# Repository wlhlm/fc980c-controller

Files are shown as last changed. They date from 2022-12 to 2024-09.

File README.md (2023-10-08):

Leopold FC980C Replacement Controller
=====================================

This PCB replaces the controller of the Leopold FC980C keyboard to allow running
alternate firmware, especially open source firmware such as [QMK][QMK]. This
project relies heavily on the prior reverse engineering work done by hasu (aka
tmk) and collaborators.

This is the first PCB I have designed and as such I suspect this will have many
areas that can be improved. I am very much looking forward to hearing feedback
about this design, if you think something can be improved please open an issue
and let me know. I will list my reasons for various design choices below, as
well as an errata section to list shortcomings of the current design that I am
aware of.

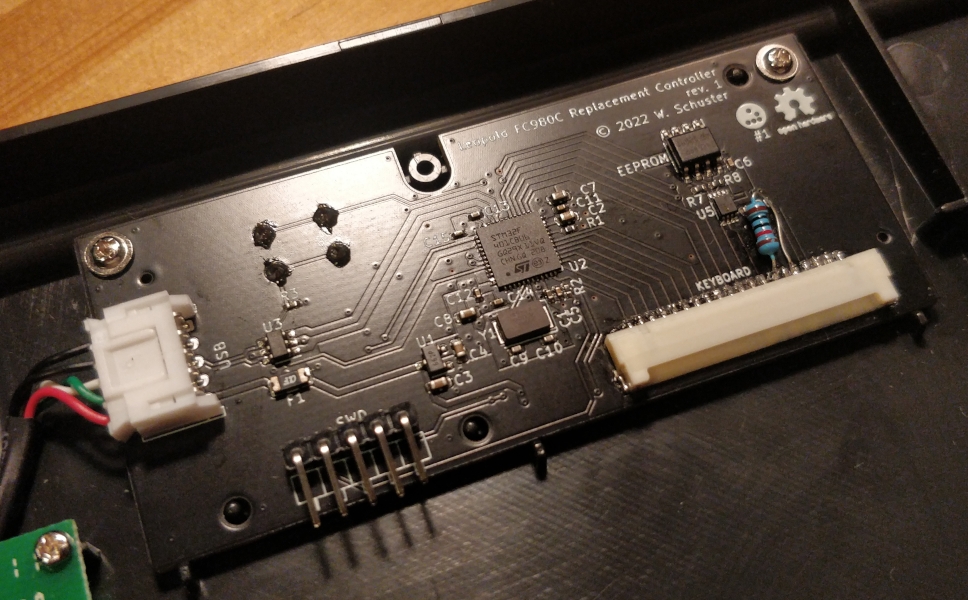
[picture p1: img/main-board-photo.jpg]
FC980C controller photo

(the resistor hand-soldered to the connector is due to a flaw of the revision 1
design, which has been fixed in revision 2)

**Specs:**
- STM32F401 MCU as found on the Blackpill boards
- Open Hardware licensed under CERN OHL-S v2
- designed to be assembled by [JLCPCB][JLC] (can of course be manufactured
  elsewhere, but board component selection has been optimized for JLC's
  component library)

**Why would anyone want a replacement keyboard controller for the FC980C?** In
case the original controller gets fried, the lack of controller replacement from
the manufacturer would otherwise mean tossing the whole (expensive) keyboard.
This board enables the usage of Free and Open Source firmware to replace the
proprietary stock firmware. Running alternate firmware allows enabling hardware
features not accessible through the original controller such as actuation point
adjustments, not to mention the plethora of software features enabled by QMK for
example.

[QMK]: https://qmk.fm/
[JLC]: https://jlcpcb.com/

Getting started
---------------

If you have received this controller fully assembled, your next step will be
firmware setup. Check the `firmware/` directory in this repository.

In case you still have to solder on the connectors, see the assembly section
below.

Assembly
--------

This PCB is intended to be manufactured and assembled by JLCPCB, **except** for
the connectors and a button on the back of the board, which most likely have to
be soldered on the PCB by hand.

The button (labled BOOT0) is through-hole and easily soldered by hand. Make sure
to place it on the bottom side, i.e. opposite side of the MCU, where the DIP
switches are on the original controller board.

The connector for the USB board (USB) is though-hole and can be hand-soldered.

The SWD header is optional and can be left unsoldered.

The connector labeled KEYBOARD is only available for surface mounting and
unfortunately not available at JLC for assembly (at least at the time of
design). Hand-soldering is a bit more challenging for this connector. Make sure
to use a healthy dose of flux and fine gauge solder wire.

Production
----------

While the PCB itself can be manufactured by a number of PCB houses, component
selection and SMD assembly is made with [JLCPCB][JLC] in mind. The
`jlcpcb/production_files` folder for each revision should include the necessary
BOM and CPL files in addition to the Gerbers. The board parameters are specified
in the PCB design file (the main parameters being a board thickness of 1.6mm and
2 copper layers). For the option "Remove Order Number", you can select "Specify
a location".

This board is compatible with JLC's "Economic PCBA" option. For option "Assembly
Side", choose "Top Side" and under "Tooling holes" you can specify "Added by
Customer".

The EEPROM (U4) and accompanying decoupling capacitor (C6) are optional. The
board should work without those populated.

[JLC]: https://jlcpcb.com/

Design review
-------------

The specific component selection is tailored to what was available at JLCPCB at
the time of design. While things like the capacitors and resistors can be easily
substituted, Larger ICs such as the USB protection, fuse, 3.3V regulator, and
MCU have not been evaluated for alternative parts.

The USB and KEYBOARD connectors interface with the existing connectors used in
the FC980C and cannot be substituted.

I don't intend to sell this controller PCB by myself and as such everyone who is
interested in the design is meant to order this directly from JLC for
themselves. As such, I've tried to minimize cost for low quantity production
runs. JLC has the concept of extended and basic parts where the former incurs a
one-time setup fee per production rund per component as those components require
additional labor for setting up the pick and place machines with the respective
components. I've tried to keep the number of extended components as low as
possible.

### MCU

The main requirements for the microcontroller were 5V tolerance and good
compatibility with QMK. I also tried to take pricing and availability for the
foreseeable future into account. My choice fell on the STM32F401 that is used in
the cheap "Blackpill" development boards. It is well supported by QMK and is
also used in [another Topre controller board project][RFR1Replacement] that
replaces the PCB of the Realforce R1 TKL keyboards.

[RFR1Replacement]: https://github.com/Cipulot/RF_R1_8-9Xu

### Protection circuitry

The 5V fuse and USB protection components have been carried forward from the
original RP2040-based design (revision 1) and have been taken from
[this][RP2040DesignGuide] RP2040 design guide.

[RP2040DesignGuide]: https://github.com/Sleepdealr/RP2040-designguide

### USB traces

USB trace width has been calculated using the KiCad built-in calculator
following a [guide on the Digikey blog][DigikeyUSBTraceGuide]. The wide traces
are caused by the board design having two layers and a thickness of 1.6mm.  This
is most likely overkill as the bandwidth requirements are very low for a
keyboard. Reviewing a number of other boards, none were using USB-specific trace
widths.

[DigikeyUSBTraceGuide]: https://www.digikey.de/en/maker/projects/how-to-route-differential-pairs-in-kicad-for-usb/45b99011f5d34879ae1831dce1f13e93

Errata
------

### Revision 2

None found thus far.

### Revision 1

The SWD header is unusable since SWDIO has been routed to the wrong pin on the
MCU (PA15 instead of PA13). This has no impact on the actual controller
functionality. Fixed in revision 2.

Unfortunately, the `KEY_STATE` pin is missing a 5V pull-up resistor. A manual
fix (such as soldering a 10k resistor between the `KEY_STATE` \[pin 14\] and 5V
pins on the `KEYBOARD` connector) is necessary. Fixed in revision 2.

Revisions
---------

### Revision 2

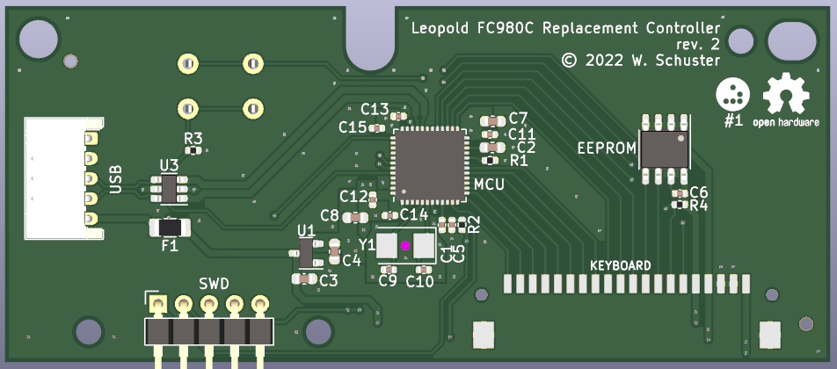
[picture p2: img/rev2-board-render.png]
rev2 PCB


Updates SWD pinout to correctly use PA13 on the MCU for SWDIO instead of PA15.

Minor position adjustments to drill holes.

Adds 5V pull-up resistor to `KEY_STATE` line.

Removes I2C level shifter to simplify BOM.

**Sample tested and working:** not yet—it is recommended to enable the options
"Confirm Production file" and "Confirm Parts Placement" when ordering from
JLC

### Revision 1

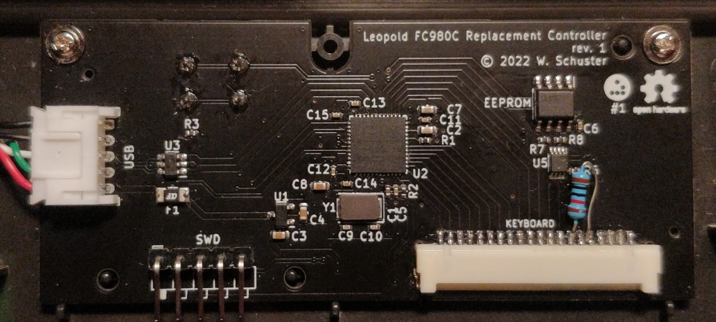
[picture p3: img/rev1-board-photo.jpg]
rev1 PCB


First design that has a chance to actually work in the FC980C. Switch to a
STM32F401 microcontroller. This MCU allows saving a couple of components
compared to the RP2040, such as USB termination resistors and external flash.

One notable addition compared to the previous revision is an optional 64Kb
EEPROM.

**Sample tested and working:** tested and issues identified (see Errata
section), working with the suggested manual fixes

### Revision 0

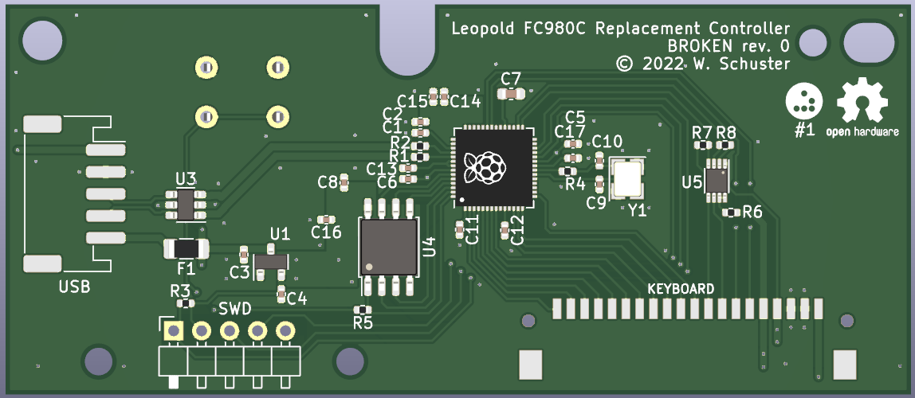
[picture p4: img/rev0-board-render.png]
rev0 PCB


The first version of this PCB uses a RP2040 controller. Unfortunately, the
FC980C electronics rely on the MCU being 5V tolerant. I have noticed this only
while triple checking the design *just* before submitting it for manufacturing.
The RP2040 is *not* 5V tolerant and would require level shifters on many I/O
lines. Because of that I decided to scrap the design and start anew, but since
the board design was pretty much complete, I'm including it in this repository
for posterity.

**Sample tested and working:** no

Acknowledgements
----------------

This replacement controller relies heavily on the [prior reverse engineering
work][GeekhackFC980CInvestigation] of the keyboard community, including
uncovering [schematics][FC660CSchematics] for the similar Leopold FC660C that
were submitted to the FCC that helped me figure out the I/O voltage
requirements. In particular, I want to thank hasu (aka tmk) who created a FC980C
replacement controller based on the ATmega32u4 MCU, publishing schematics and an
[open source firmware implementation][TMKFC980C] for tmk that has been
[ported][QMKFC980C] to QMK.

Thanks to Toocanzs#5098 from the QMK Discord for helping me with the crystal
load capacitor calculation.

The PCB has been designed using KiCad 6 and production files have been exported
using [Bouni's JLCPCB tools plugin][BouniJLCPlugin].

[GeekhackFC980CInvestigation]: https://geekhack.org/index.php?topic=90681.0
[FC660CSchematics]: https://fccid.io/pdf.php?id=1888185
[TMKFC980C]: https://github.com/tmk/tmk_keyboard/tree/master/keyboard/fc980c
[QMKFC980C]: https://github.com/qmk/qmk_firmware/tree/f21443d6a2be8e2068164f0f3646a175ffed2df4/keyboards/fc980c
[BouniJLCPlugin]: https://github.com/Bouni/kicad-jlcpcb-tools

Resources
---------

These are various resources, that helped me designing my first PCB:

- STM AN4488 - Getting started with STM32F4xxxx MCU hardware development
- [I2C pullup recommendation by adafruit](https://learn.adafruit.com/working-with-i2c-devices/pull-up-resistors),
  [I2C pullup calculator](http://lembke.eu/arduinoablage/20201103i2cpullupcalculator/)
- [I2C Design Mathematics: Capacitance and Resistance](https://www.allaboutcircuits.com/technical-articles/i2c-design-mathematics-capacitance-and-resistance/)
- [Can an STM32 chip directly interface with a 5V I2C bus?](https://electronics.stackexchange.com/questions/50435/can-i-directly-interface-to-5v-i2c-devices-with-an-stm32-running-on-1-8v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)
- [5V to 3.3V logic level translation/conversion/shifting](https://next-hack.com/index.php/2017/09/15/how-to-interface-a-5v-output-to-a-3-3v-input/)
- STM AN2867 - Oscillator design guide for STM8S, STM8A and STM32
  microcontrollers
- [Crystal capacitor guide by adafruit](https://blog.adafruit.com/2012/01/24/choosing-the-right-crystal-and-caps-for-your-design/)
- [STM32 Oscillator Calculator](https://helios.wh2.tu-dresden.de/~benni_koch/stmcalculator/)
- [Crystal Oscillator Design](https://hoani.net/posts/blog/2017-01-19-oscillator-design/)
- [Can the STM32-internal pull-up resistors be used with 5V lines?](http://forums.netduino.com/index.php?/topic/10401-guidance-using-5v-signals-with-pull-upspull-downs/)
- [KiCad differential pair routing guide by Digikey](https://www.digikey.de/en/maker/projects/how-to-route-differential-pairs-in-kicad-for-usb/45b99011f5d34879ae1831dce1f13e93)
- [RP2040 hardware design guide by Sleepdealr](https://github.com/Sleepdealr/RP2040-designguide)
- [KiCad 6 STM32 tutorial by Phil's Lab](https://www.youtube.com/watch?v=aVUqaB0IMh4)
- [KiCad PCB tutorial by MalphasWats](https://github.com/MalphasWats/hawk)
- [Layout Design Guide by Toradex](https://docs.toradex.com/102492-layout-design-guide.pdf)
- [Effective PCB Design by NXP](https://www.nxp.com/files-static/training_pdf/WBNR_PCBDESIGN.pdf)

This helped with the software matrix scanning implementation:

- [Using STM32 GPIO with ChibiOS PAL Driver](https://www.playembedded.org/blog/stm32-gpio-chibios-pal/)

This helped me immensensly in figuring out the FC980C-specific hardware
requirements for the FC980C controller:

- [FC980C pinout](https://github.com/tmk/tmk_keyboard/blob/4df8a27f7220c5f801f16151d31d4db8e563c2fa/keyboard/fc980c/README.md) by tmk
- FC660C [schematic](https://fccid.io/pdf.php?id=1888185) and [BOM](https://fccid.io/pdf.php?id=1888184)

License
-------

Copyright © 2022 Wilhelm Schuster

This PCB design is licensed under the CERN-OHL-S v2. See the LICENSE file in
each of the revision folders for the license text. This license is strongly
reciprocal and is similar in spirit to the GPL, but specifically focuses on
hardware.

The firmware portion of this project is licensed under GPL-2-or-later in
accordance with the QMK project. See the LICENSE file in the firmware folder for
the license text.

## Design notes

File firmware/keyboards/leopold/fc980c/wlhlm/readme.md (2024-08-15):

# Leopold FC980C replacement controller

wlhlm FC980C replacement controller render

* Keyboard Maintainer: [wlhlm](https://github.com/wlhlm)
* Hardware Supported: rev. 1, rev. 2
* [PCB Source](https://github.com/wlhlm/fc980c-controller/)

Make example for this keyboard (after setting up your build environment):

    make leopold/fc980c/wlhlm:default

See the [build environment setup](https://docs.qmk.fm/#/getting_started_build_tools) and the [make instructions](https://docs.qmk.fm/#/getting_started_make_guide) for more information. Brand new to QMK? Start with our [Complete Newbs Guide](https://docs.qmk.fm/#/newbs).

## Flashing the firmware onto the keyboard

To be able to flash the controller, it first has to be brought into bootloader mode. There are three ways this can be accomplished:

- Hold the `BOOT0` button at the back of the controller board (also accessible with the case installed) pressed while plugging the board into USB.
- Hold the `Escape` key while plugging the board into USB (requires QMK to already be flashed onto the controller).
- Press `Fn+Esc` (requires QMK to already be flashed onto the controller).

After entering bootloader mode, new firmware can be flashed. Make example for flashing this keyboard:

    make leopold/fc980c/wlhlm:default:flash

## Actuation point adjustment

Topre keyboards such as the FC980C are based around capacitive sense and allow adjustment of the actuation point. This feature is not supported by the stock FC980C controller, this replacement controller however unlocks said functionality. Check the `actuation_point_example` keymap for guidance.

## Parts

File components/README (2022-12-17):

This contains KiCad parts libraries required for the FC980C controller PCB.

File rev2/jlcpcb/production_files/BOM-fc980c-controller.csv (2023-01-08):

Comment | Designator | Footprint | LCSC
8MHz Cl 20pF | Y1 | Crystal_SMD_5032-2Pin_5.0x3.2mm | C115962
STM32F401CBUx | U2 | QFN-48-1EP_7x7mm_P0.5mm_EP5.6x5.6mm | C118825
100nF | C11,C12,C13,C14,C15,C5,C6 | C_0402_1005Metric | C1525
20pF | C10,C9 | C_0402_1005Metric | C1554
USB | J2 | JST_PH_S5B-PH-K_1x05_P2.00mm_Horizontal | C157923
1uF | C3,C4,C8 | C_0603_1608Metric | C15849
4.7uF | C2 | C_0603_1608Metric | C19666
10uF | C7 | C_0603_1608Metric | C19702
10k | R1,R2,R3,R4 | R_0402_1005Metric | C25744
USBLC6-2SC6 | U3 | SOT-23-6 | C2827654
BOOT0 | SW1 | SW_PUSH_6mm | C2834895
KEYBOARD | J3 | HRS_DF14_20P | C506679
1uF | C1 | C_0402_1005Metric | C52923
XC6206P332MR | U1 | SOT-23 | C5446
500mA | F1 | Fuse_1206_3216Metric | C70076
M24C64-RMN6TP | U4 | SOIC-8_3.9x4.9mm_P1.27mm | C79988
SWD | J1 | PinHeader_1x05_P2.54mm_Horizontal

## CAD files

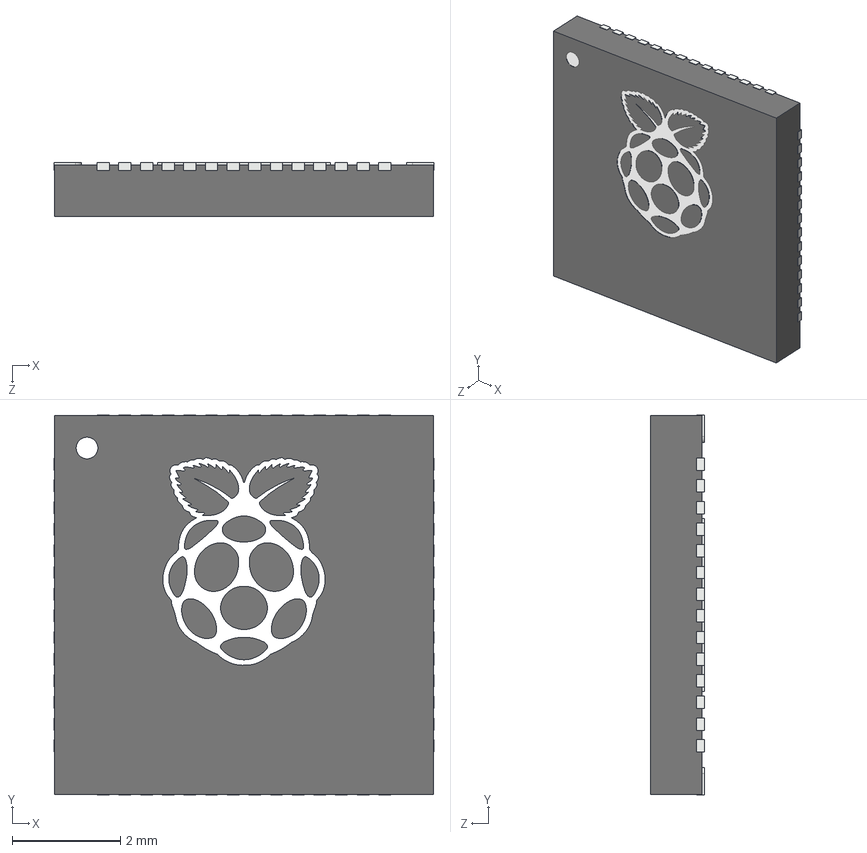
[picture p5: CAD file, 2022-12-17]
components/sleep-lib/RP2040_QFN_PACKAGE.step
7.02 x 7.02 x 1.00 mm

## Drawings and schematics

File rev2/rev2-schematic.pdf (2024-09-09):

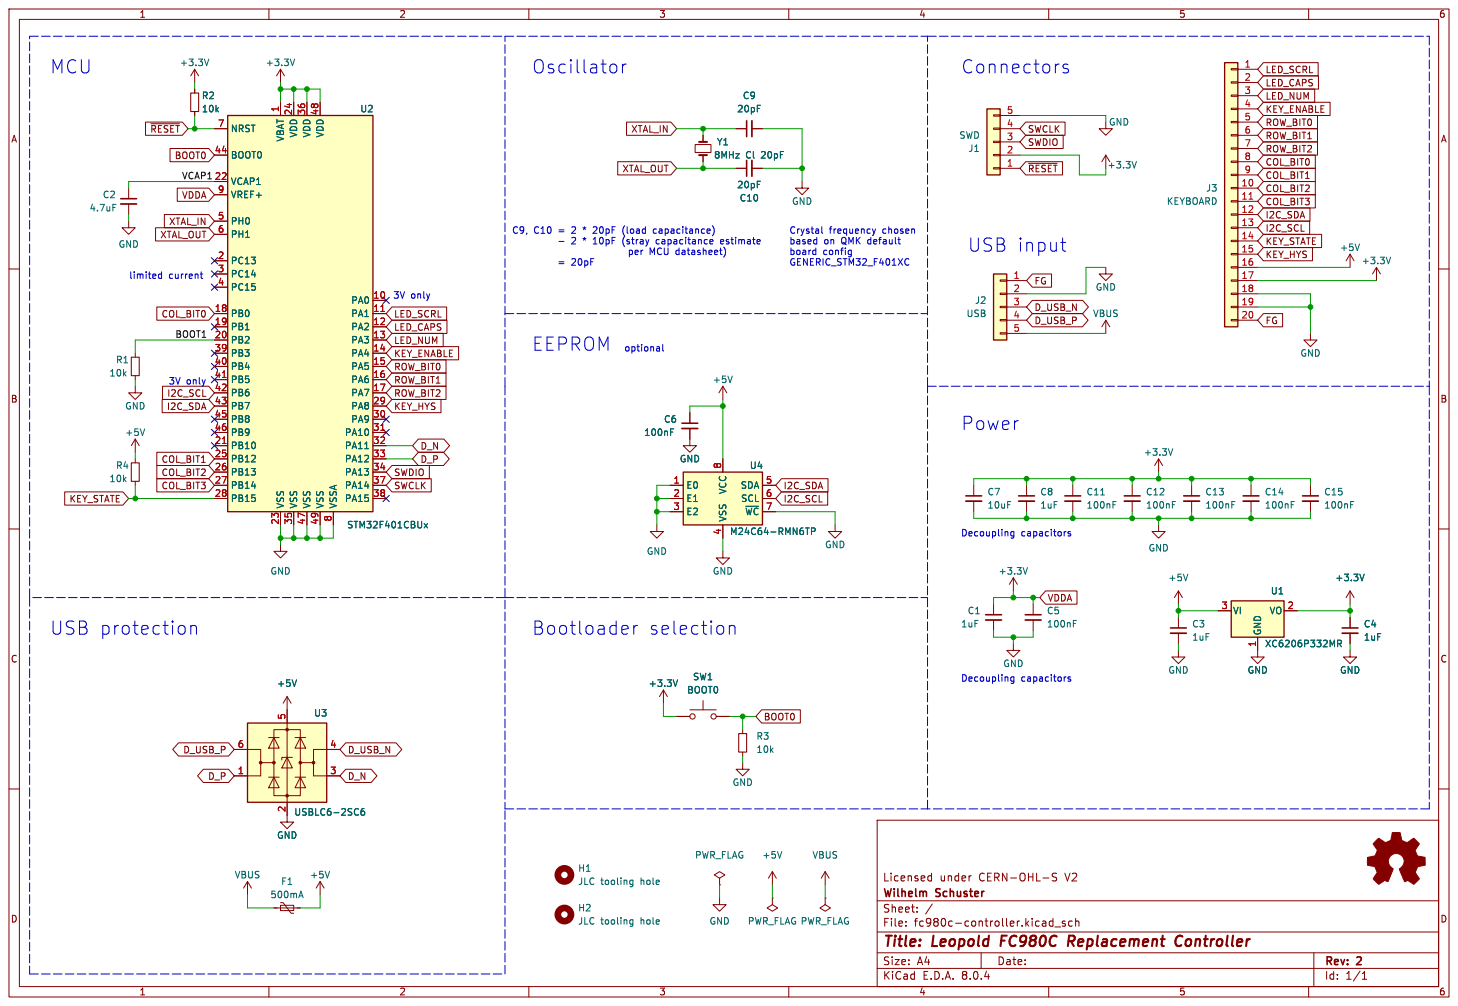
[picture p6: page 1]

1 PA0 10 PA1 11 PA2 12 PA3 13 PA4 14 PA5 15 PA6 16 PA7 17 PB0 18 PB1 19 PC13 2 PB2 20 PB10 21 VCAP1 22 VSS 23 VDD 24 PB12 25 PB13 26 PB14 27 PB15 28 PA8 29 PC14 3 PA9 30 PA10 31 PA11 32 PA12 33 PA13 34 VSS 35 VDD 36 PA14 37 PA15 38 PB3 39 PC15 4 PB4 40 PB5 41 PB6 42 PB7 43 BOOT0 44 PB8 45 PB9 46 VSS 47 VDD 48 VSS 49 PH0 5 PH1 6 NRST 7 VSSA

4 SDA 5 SCL 6 ~{WC}7 VCC

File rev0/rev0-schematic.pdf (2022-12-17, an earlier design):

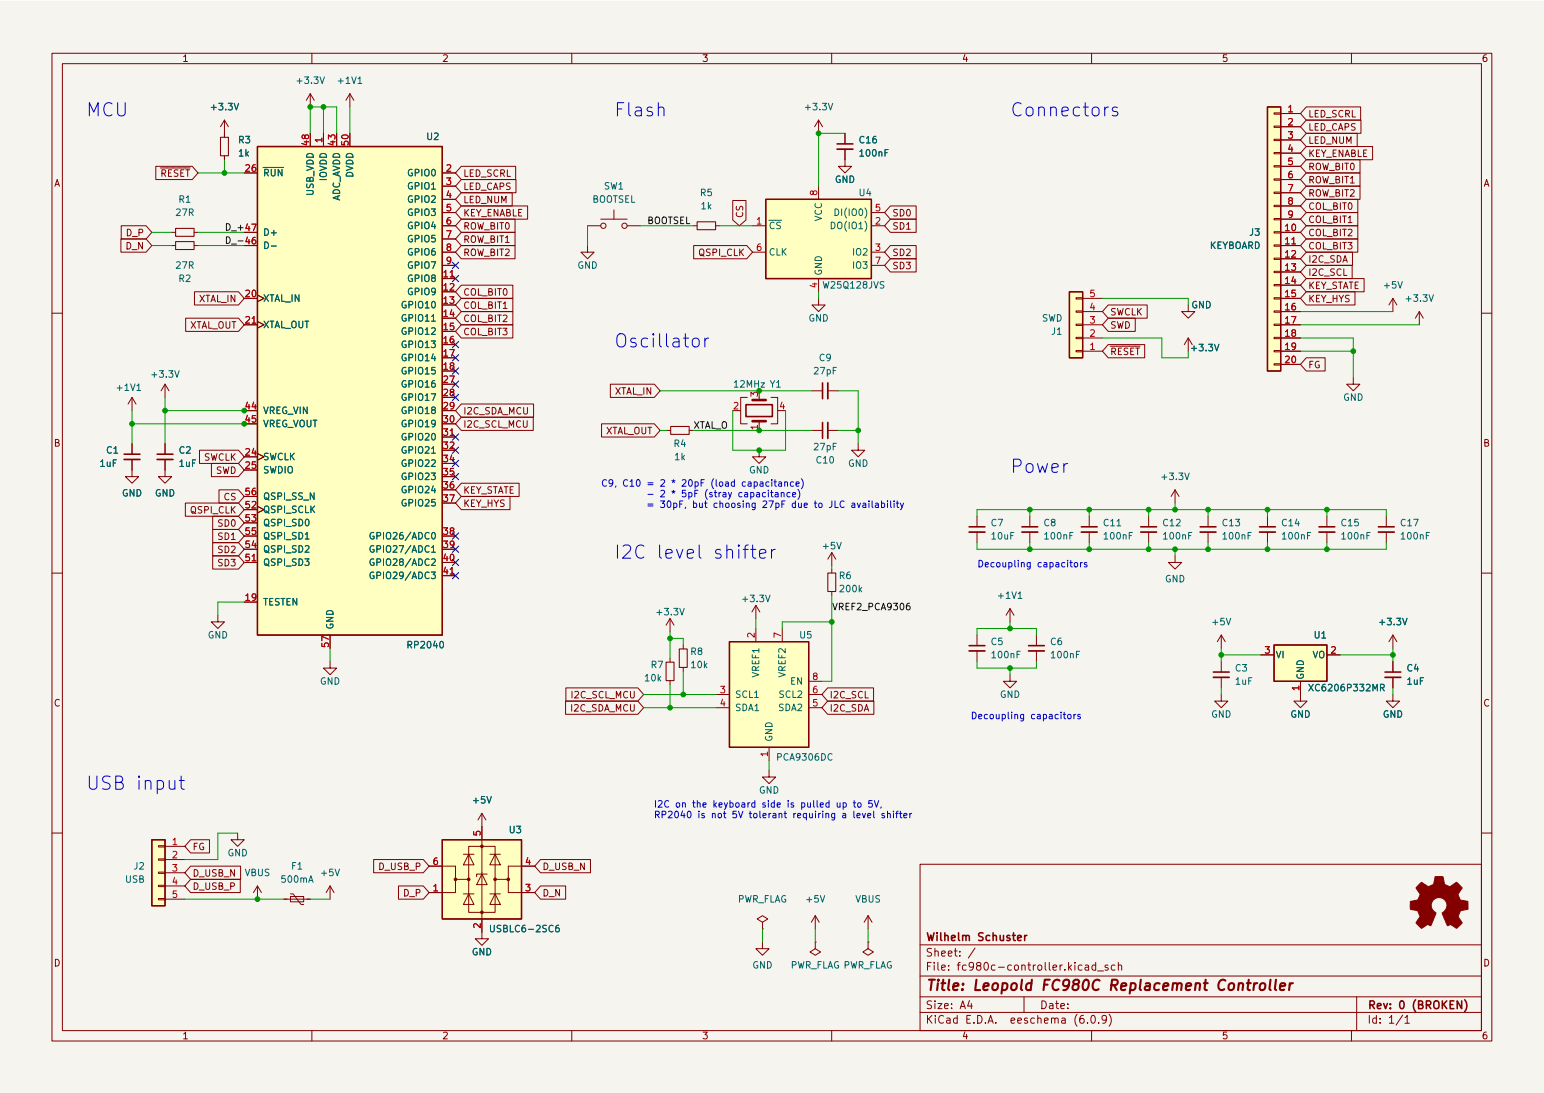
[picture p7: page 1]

1 GPIO8 11 GPIO9 12 GPIO10 13 GPIO11 14 GPIO12 15 GPIO13 16 GPIO14 17 GPIO15 18 TESTEN 19 GPIO0 2 XTAL_IN 20 XTAL_OUT 21 SWCLK 24 SWDIO 25 ~{RUN} 26 GPIO16 27 GPIO17 28 GPIO18 29 GPIO1 3 GPIO19 30 GPIO20 31 GPIO21 32 GPIO22 34 GPIO23 35 GPIO24 36 GPIO25 37 GPIO26/ADC0 38 GPIO27/ADC1 39 GPIO2 4 GPIO28/ADC2 40 GPIO29/ADC3 41 ADC_AVDD 43 VREG_VIN 44 VREG_VOUT 45 D- 46 D+ 47 USB_VDD 48 GPIO3 5 DVDD 50 QSPI_SD3 51 QSPI_SCLK 52 QSPI_SD0 53 QSPI_SD2 54 QSPI_SD1 55 QSPI_SS_N 56 GND 57 GPIO4 6 GPIO5 7 GPIO6 8 GPIO7 9 U2 RP2040 C6

1 GPIO8 11 GPIO9 12 GPIO10 13 GPIO11 14 GPIO12 15 GPIO13 16 GPIO14 17 GPIO15 18 TESTEN 19 GPIO0 2 XTAL_IN 20 XTAL_OUT 21 SWCLK 24 SWDIO 25 ~{RUN} 26 GPIO16 27 GPIO17 28 GPIO18 29 GPIO1 3 GPIO19 30 GPIO20 31 GPIO21 32 GPIO22 34 GPIO23 35 GPIO24 36 GPIO25 37 GPIO26/ADC0 38 GPIO27/ADC1 39 GPIO2 4 GPIO28/ADC2 40 GPIO29/ADC3 41 ADC_AVDD 43 VREG_VIN 44 VREG_VOUT 45 D- 46 D+ 47 USB_VDD 48 GPIO3 5 DVDD 50 QSPI_SD3 51 QSPI_SCLK 52 QSPI_SD0 53 QSPI_SD2 54 QSPI_SD1 55 QSPI_SS_N 56 GND 57 GPIO4 6 GPIO5 7 GPIO6 8 GPIO7 9 +5V GND

C9, C10 = 2 * 20pF (load capacitance)
- 2 * 5pF (stray capacitance)
= 30pF, but choosing 27pF due to JLC availability

I2C on the keyboard side is pulled up to 5V,
RP2040 is not 5V tolerant requiring a level shifter

File: fc980c-controller.kicad_sch Sheet: / Wilhelm Schuster

Id: 1/1 Title: Leopold FC980C Replacement Controller

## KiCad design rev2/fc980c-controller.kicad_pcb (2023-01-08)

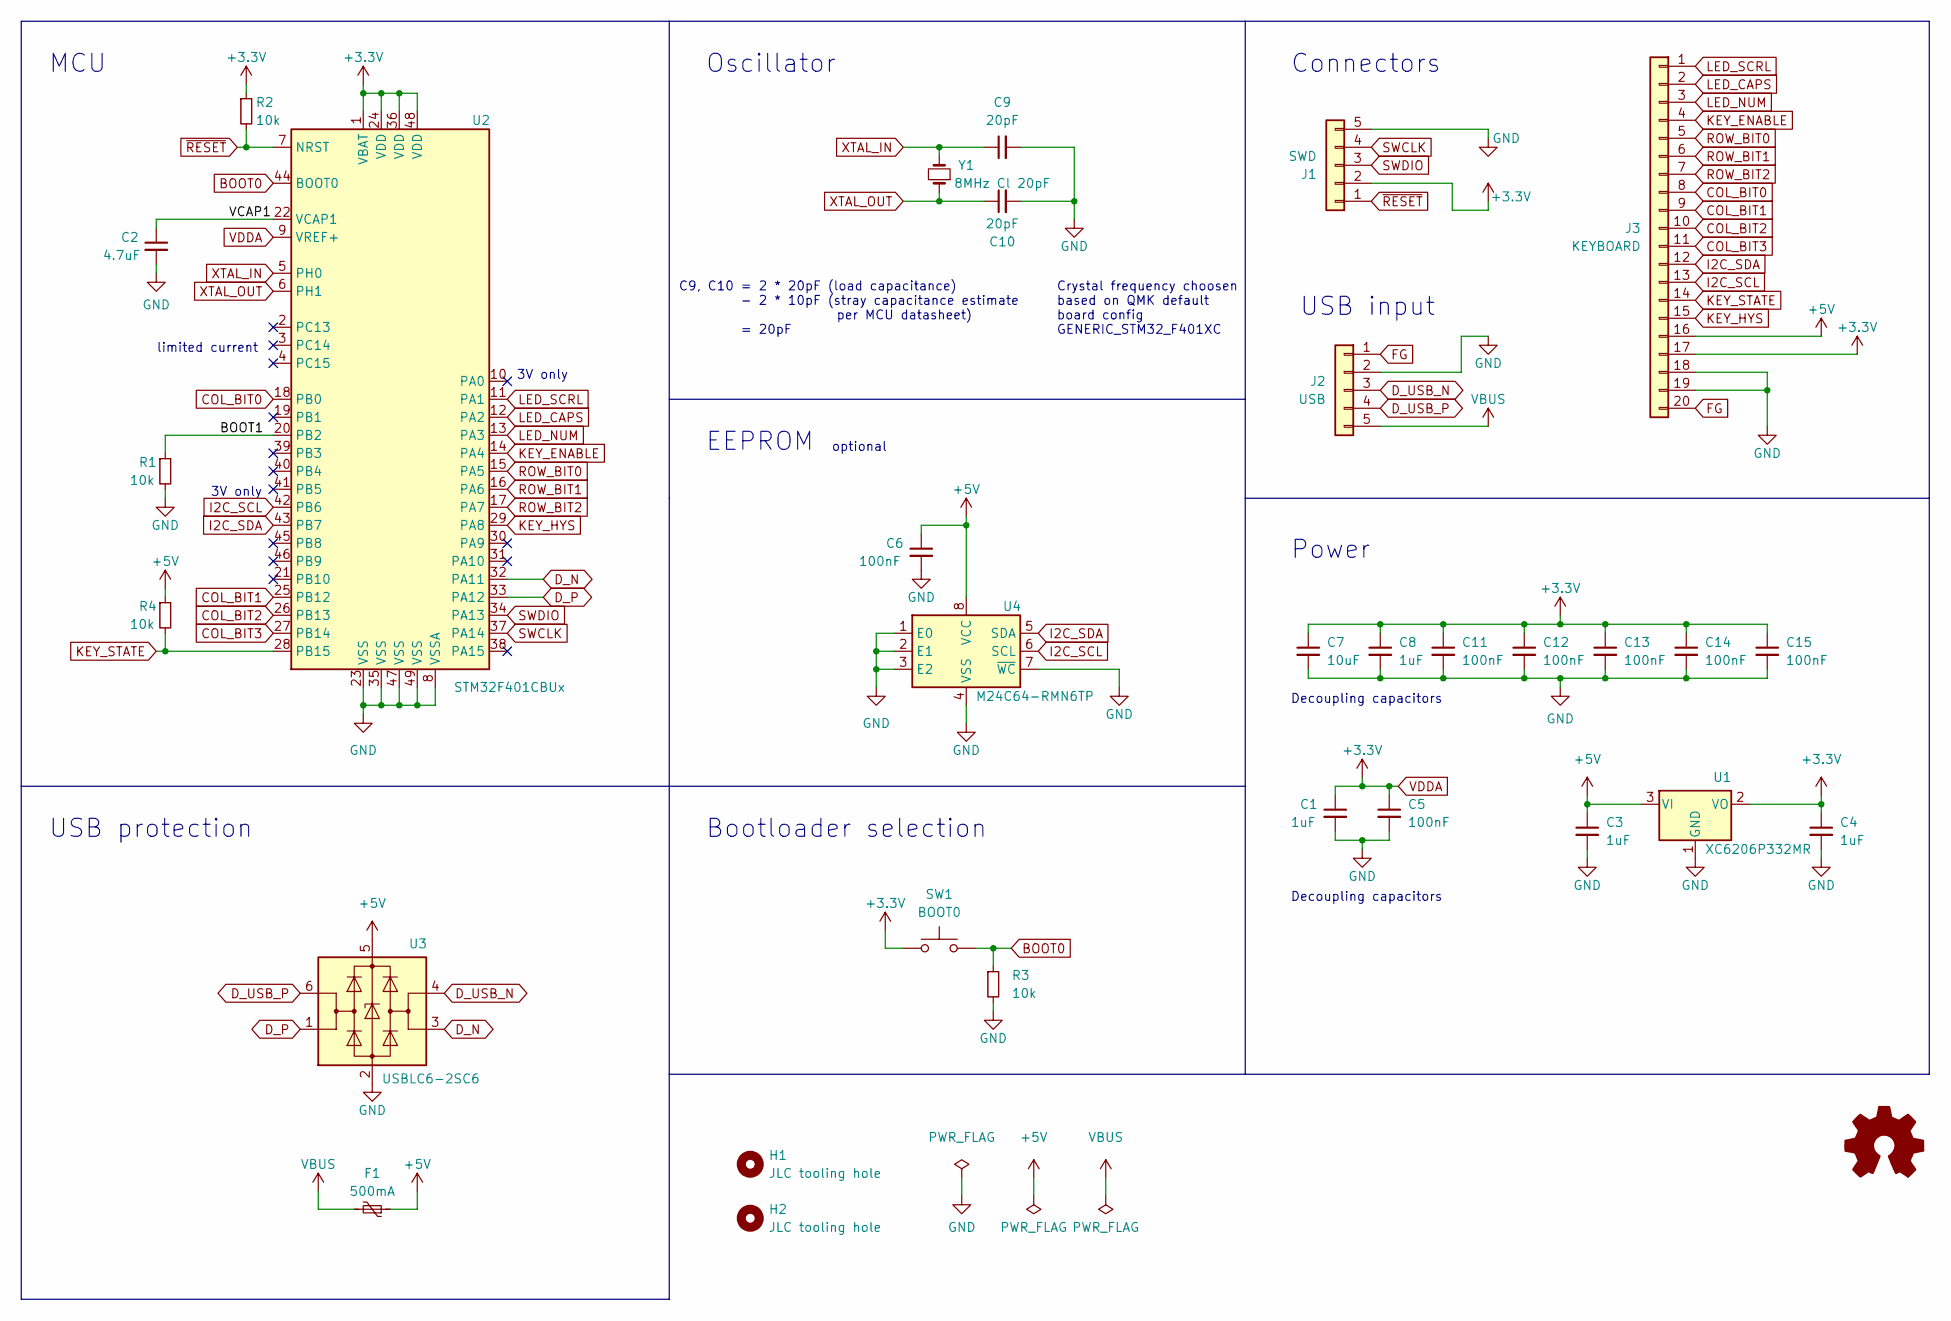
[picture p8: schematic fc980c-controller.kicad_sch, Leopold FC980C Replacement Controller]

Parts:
C1: 1uF; C_0402_1005Metric
C2: 4.7uF; C_0603_1608Metric
C3, C4, C8: 1uF; C_0603_1608Metric
C5, C6, C11, C12, C13, C14, C15: 100nF; C_0402_1005Metric
C7: 10uF; C_0603_1608Metric
C9, C10: 20pF; C_0402_1005Metric
F1: 500mA; Fuse_1206_3216Metric
H1, H2: JLC tooling hole; JLC_tooling_hole
J1: SWD; PinHeader_1x05_P2.54mm_Horizontal
J2: USB; JST_PH_S5B-PH-K_1x05_P2.00mm_Horizontal
J3: KEYBOARD; HRS_DF14_20P
LOGO1: Logo_Open_Hardware_Small; OSHW-Logo2_7.3x6mm_SilkScreen
R1, R2, R3, R4: 10k; R_0402_1005Metric
SW1: BOOT0; SW_PUSH_6mm
U1: XC6206P332MR; SOT-23
U2: STM32F401CBUx; QFN-48-1EP_7x7mm_P0.5mm_EP5.6x5.6mm
U3: USBLC6-2SC6; SOT-23-6
U4: M24C64-RMN6TP; SOIC-8_3.9x4.9mm_P1.27mm
Y1: 8MHz Cl 20pF; Crystal_SMD_5032-2Pin_5.0x3.2mm

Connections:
+5V: C3.1, C6.1, F1.1, J3.16, R4.1, U1.3 (VI), U3.5 (VBUS), U4.8 (VCC)
/BOOT1: R1.1, U2.20 (PB2)
/VCAP1: C2.1, U2.22 (VCAP1)
BOOT0: R3.1, SW1.2, U2.44 (BOOT0)
COL_BIT0: J3.8, U2.18 (PB0)
COL_BIT1: J3.9, U2.25 (PB12)
COL_BIT2: J3.10, U2.26 (PB13)
COL_BIT3: J3.11, U2.27 (PB14)
D_N: U2.32 (PA11), U3.3 (I/O2)
D_P: U2.33 (PA12), U3.1 (I/O1)
D_USB_N: J2.3, U3.4 (I/O2)
D_USB_P: J2.4, U3.6 (I/O1)
FG: J2.1, J3.20
GND: C1.2, C2.2, C3.2, C4.2, C5.2, C6.2, C7.2, C8.2, C9.2, C10.2, C11.2, C12.2, C13.2, C14.2, C15.2, J1.5, J2.2, J3.18, J3.19, J3.21, J3.22, R1.2, R3.2, U1.1 (GND), U2.8 (VSSA), U2.23 (VSS), U2.35 (VSS), U2.47 (VSS), U2.49 (VSS), U3.2 (GND), U4.1 (E0), U4.2 (E1), U4.3 (E2), U4.4 (VSS), U4.7 (~WC)
I2C_SCL: J3.13, U2.42 (PB6), U4.6 (SCL)
I2C_SDA: J3.12, U2.43 (PB7), U4.5 (SDA)
KEY_ENABLE: J3.4, U2.14 (PA4)
KEY_HYS: J3.15, U2.29 (PA8)
KEY_STATE: J3.14, R4.2, U2.28 (PB15)
LED_CAPS: J3.2, U2.12 (PA2)
LED_NUM: J3.3, U2.13 (PA3)
LED_SCRL: J3.1, U2.11 (PA1)
ROW_BIT0: J3.5, U2.15 (PA5)
ROW_BIT1: J3.6, U2.16 (PA6)
ROW_BIT2: J3.7, U2.17 (PA7)
SWCLK: J1.4, U2.37 (PA14)
SWDIO: J1.3, U2.34 (PA13)
VBUS: F1.2, J2.5
VDDA: C1.1, C4.1, C5.1, C7.1, C8.1, C11.1, C12.1, C13.1, C14.1, C15.1, J1.2, J3.17, R2.1, SW1.1, U1.2 (VO), U2.1 (VBAT), U2.9 (VREF+), U2.24 (VDD), U2.36 (VDD), U2.48 (VDD)
XTAL_IN: C9.1, U2.5 (PH0), Y1.2
XTAL_OUT: C10.1, U2.6 (PH1), Y1.1
~RESET: J1.1, R2.2, U2.7 (NRST)

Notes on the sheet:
Decoupling capacitors
3V only
Oscillator
C9, C10 = 2 * 20pF (load capacitance) - 2 * 10pF (stray capacitance estimate per MCU datasheet) = 20pF
Power
limited current
Bootloader selection
Connectors
Crystal frequency choosen based on QMK default board config GENERIC_STM32_F401XC
USB input
USB protection
optional
MCU
EEPROM

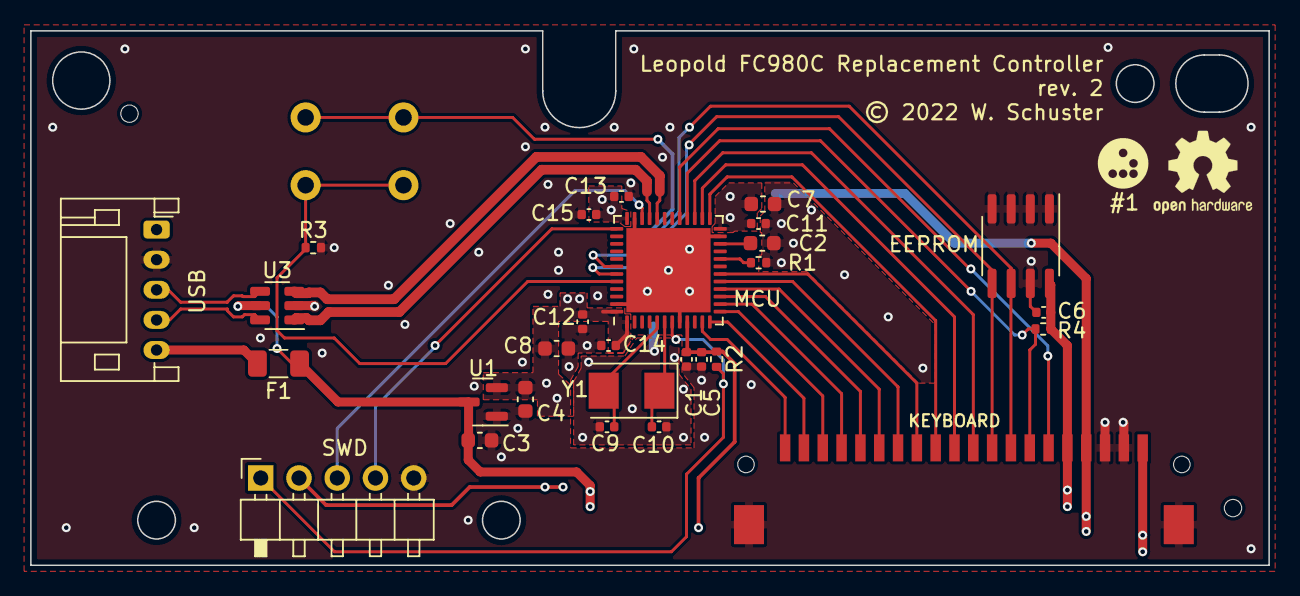
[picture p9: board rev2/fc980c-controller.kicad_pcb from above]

Board: 2 copper layers, 82.2 x 35.5 mm, 32 parts (1 on the bottom side), 32 nets.

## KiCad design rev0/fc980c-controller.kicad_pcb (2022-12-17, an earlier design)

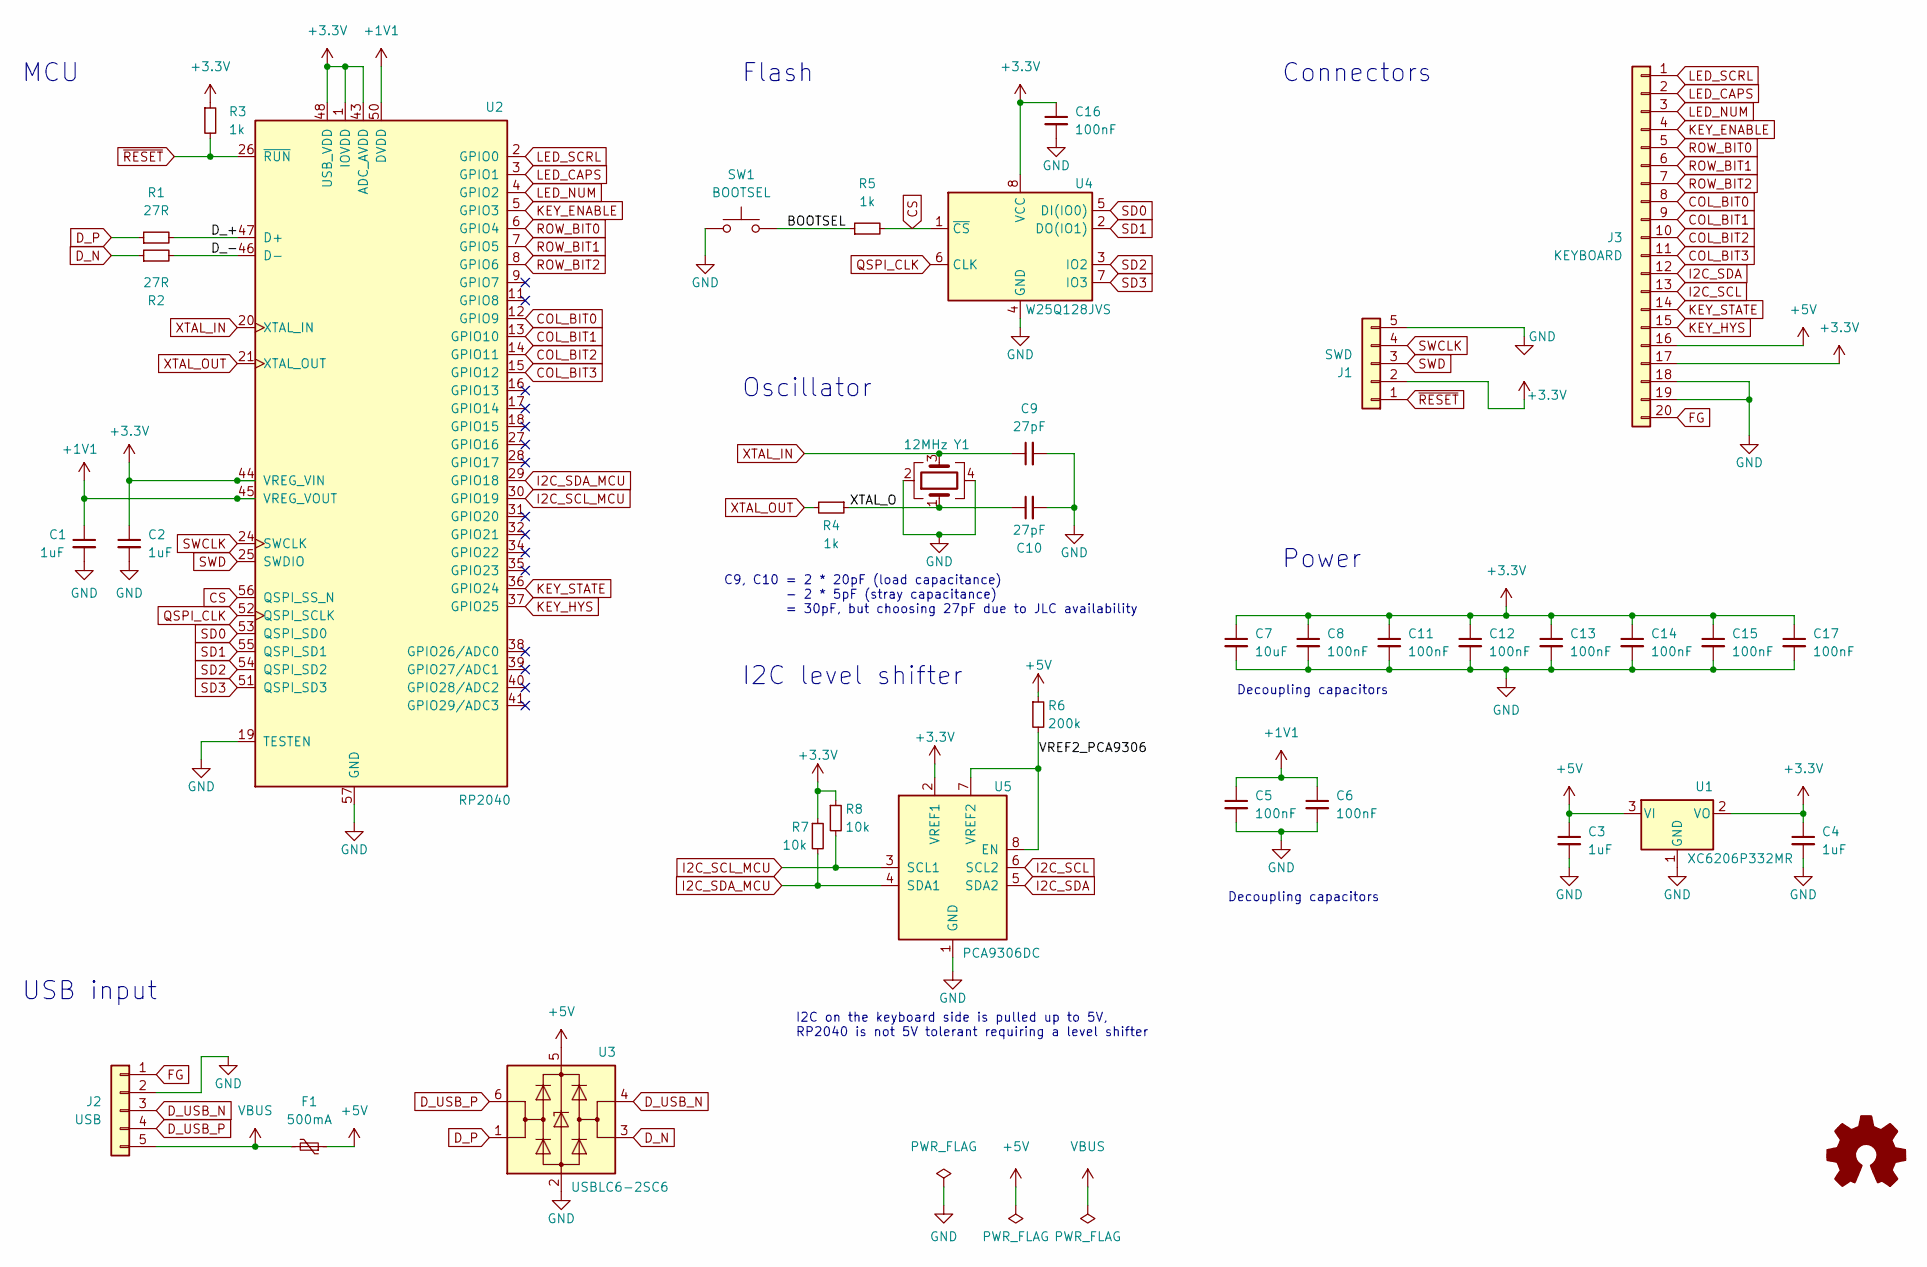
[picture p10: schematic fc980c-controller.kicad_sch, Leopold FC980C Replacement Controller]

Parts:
C1, C2, C3, C4: 1uF; C_0402_1005Metric
C5, C6, C8, C11, C12, C13, C14, C15, C16, C17: 100nF; C_0402_1005Metric
C7: 10uF; C_0603_1608Metric
C9, C10: 27pF; C_0402_1005Metric
F1: 500mA; Fuse_1206_3216Metric
J1: SWD; PinHeader_1x05_P2.54mm_Horizontal
J2: USB; JST_PH_S5B-PH-SM4-TB_1x05-1MP_P2.00mm_Horizontal
J3: KEYBOARD; HRS_DF14_20P
LOGO1: Logo_Open_Hardware_Small; OSHW-Logo2_7.3x6mm_SilkScreen
R1, R2: 27R; R_0402_1005Metric
R3, R4, R5: 1k; R_0402_1005Metric
R6: 200k; R_0402_1005Metric
R7, R8: 10k; R_0402_1005Metric
SW1: BOOTSEL; SW_PUSH_6mm
U1: XC6206P332MR; SOT-23
U2: RP2040; RP2040-QFN-56
U3: USBLC6-2SC6; SOT-23-6
U4: W25Q128JVS; SOIC-8_5.23x5.23mm_P1.27mm
U5: PCA9306DC; VSSOP-8_2.3x2mm_P0.5mm
Y1: 12MHz; Crystal_SMD_3225-4Pin_3.2x2.5mm

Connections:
+1V1: C1.1, C5.1, C6.1, U2.23 (DVDD), U2.45 (VREG_VOUT), U2.50 (DVDD)
+3.3V: C2.1, C4.1, C7.1, C8.1, C11.1, C12.1, C13.1, C14.1, C15.1, C16.1, C17.1, J1.2, J3.17, R3.1, R7.1, R8.1, U1.2 (VO), U2.1 (IOVDD), U2.10 (IOVDD), U2.22 (IOVDD), U2.33 (IOVDD), U2.42 (IOVDD), U2.43 (ADC_AVDD), U2.44 (VREG_VIN), U2.48 (USB_VDD), U2.49 (IOVDD), U4.8 (VCC), U5.2 (VREF1)
+5V: C3.1, F1.1, J3.16, R6.1, U1.3 (VI), U3.5 (VBUS)
/BOOTSEL: R5.1, SW1.2
/D_+: R1.2, U2.47 (D+)
/D_-: R2.2, U2.46 (D-)
/VREF2_PCA9306: R6.2, U5.7 (VREF2), U5.8 (EN)
/XTAL_O: C10.1, R4.1, Y1.1
COL_BIT0: J3.8, U2.12 (GPIO9)
COL_BIT1: J3.9, U2.13 (GPIO10)
COL_BIT2: J3.10, U2.14 (GPIO11)
COL_BIT3: J3.11, U2.15 (GPIO12)
CS: R5.2, U2.56 (QSPI_SS_N), U4.1 (~CS)
D_N: R2.1, U3.3 (I/O2)
D_P: R1.1, U3.1 (I/O1)
D_USB_N: J2.3, U3.4 (I/O2)
D_USB_P: J2.4, U3.6 (I/O1)
FG: J2.1, J3.20
GND: C1.2, C2.2, C3.2, C4.2, C5.2, C6.2, C7.2, C8.2, C9.2, C10.2, C11.2, C12.2, C13.2, C14.2, C15.2, C16.2, C17.2, J1.5, J2.2, J3.18, J3.19, SW1.1, U1.1 (GND), U2.19 (TESTEN), U2.57 (GND), U3.2 (GND), U4.4 (GND), U5.1 (GND), Y1.2, Y1.4
I2C_SCL: J3.13, U5.6 (SCL2)
I2C_SCL_MCU: R8.2, U2.30 (GPIO19), U5.3 (SCL1)
I2C_SDA: J3.12, U5.5 (SDA2)
I2C_SDA_MCU: R7.2, U2.29 (GPIO18), U5.4 (SDA1)
KEY_ENABLE: J3.4, U2.5 (GPIO3)
KEY_HYS: J3.15, U2.37 (GPIO25)
KEY_STATE: J3.14, U2.36 (GPIO24)
LED_CAPS: J3.2, U2.3 (GPIO1)
LED_NUM: J3.3, U2.4 (GPIO2)
LED_SCRL: J3.1, U2.2 (GPIO0)
QSPI_CLK: U2.52 (QSPI_SCLK), U4.6 (CLK)
ROW_BIT0: J3.5, U2.6 (GPIO4)
ROW_BIT1: J3.6, U2.7 (GPIO5)
ROW_BIT2: J3.7, U2.8 (GPIO6)
SD0: U2.53 (QSPI_SD0), U4.5 (DI(IO0))
SD1: U2.55 (QSPI_SD1), U4.2 (DO(IO1))
SD2: U2.54 (QSPI_SD2), U4.3 (IO2)
SD3: U2.51 (QSPI_SD3), U4.7 (IO3)
SWCLK: J1.4, U2.24 (SWCLK)
SWD: J1.3, U2.25 (SWDIO)
VBUS: F1.2, J2.5
XTAL_IN: C9.1, U2.20 (XTAL_IN), Y1.3
XTAL_OUT: R4.2, U2.21 (XTAL_OUT)
~RESET: J1.1, R3.2, U2.26 (~RUN)

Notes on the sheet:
Oscillator
I2C level shifter
C9, C10 = 2 * 20pF (load capacitance) - 2 * 5pF (stray capacitance) = 30pF, but choosing 27pF due to JLC availability
Power
Decoupling capacitors
Connectors
Flash
I2C on the keyboard side is pulled up to 5V, RP2040 is not 5V tolerant requiring a level shifter
USB input
MCU

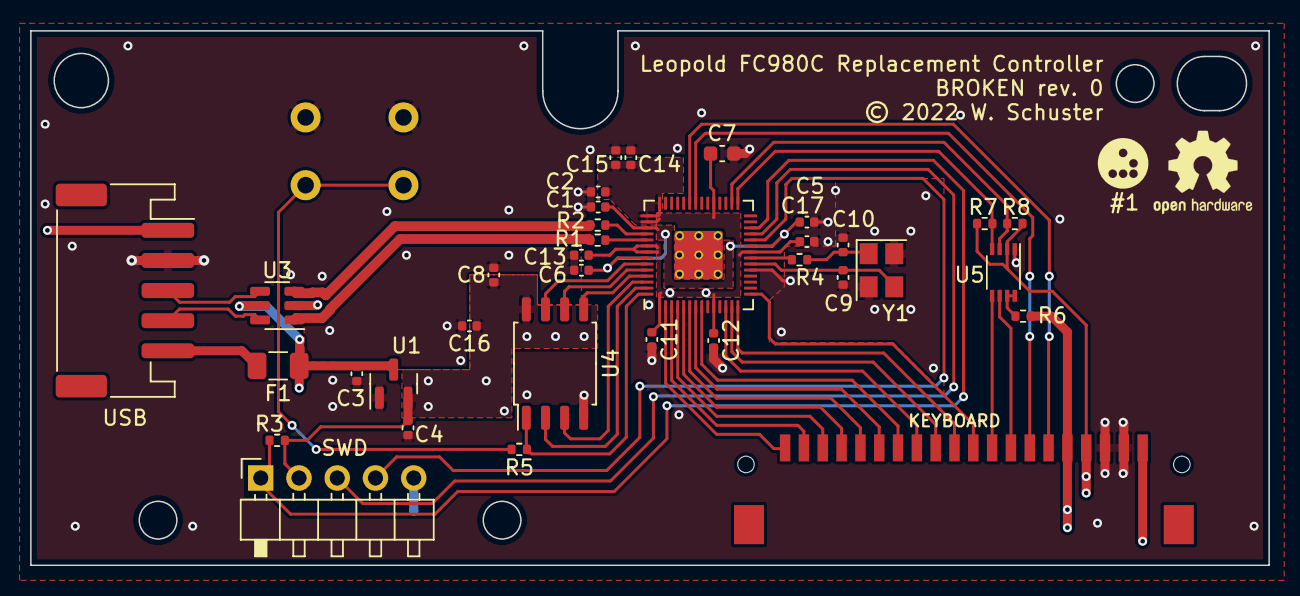
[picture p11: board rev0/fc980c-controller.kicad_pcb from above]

Board: 2 copper layers, 82.2 x 35.5 mm, 37 parts (1 on the bottom side), 43 nets.

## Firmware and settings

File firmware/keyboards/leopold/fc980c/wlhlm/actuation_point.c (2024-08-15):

// Copyright 2024 Wilhelm Schuster
// based on work by Jun Wako and Balz Guenat
// SPDX-License-Identifier: GPL-2.0-or-later

#include "actuation_point.h"

#include "i2c_master.h"
#include "debug.h"
#include "util.h"
#include "wait.h"

#include QMK_KEYBOARD_H

#define ACTUATION_POINT_I2C_TIMEOUT 100

///////////////////////////////////////////////////////////////////////////////
//
// AD5258 I2C digital potentiometer
// https://www.analog.com/media/en/technical-documentation/data-sheets/AD5258.pdf
//
#define AD5258_ADDR (0b0011000 << 1) // QMK I2C API requires shifting the address one bit to the left
#define AD5258_INST_RDAC 0x00
#define AD5258_INST_EEPROM 0x20
#define AD5258_INST_NOP 0x80
#define AD5258_INST_RESTORE 0xA0

#define AD5258_RDAC_MAX 63
#define AD5258_RDAC_MIN 0

// read RDAC register
int8_t actuation_point_read_rdac(void) {
    uint8_t ret = 0;

    i2c_status_t e = i2c_read_register(AD5258_ADDR, AD5258_INST_RDAC, &ret, 1, ACTUATION_POINT_I2C_TIMEOUT);
    if (e != I2C_STATUS_SUCCESS) {
        return -1;
    }

    return MIN(AD5258_RDAC_MAX, ret);
};

int8_t actuation_point_read_eeprom(void) {
    uint8_t ret = 0;

    i2c_status_t e = i2c_read_register(AD5258_ADDR, AD5258_INST_EEPROM, &ret, 1, ACTUATION_POINT_I2C_TIMEOUT);
    if (e != I2C_STATUS_SUCCESS) {
        return -1;
    }

    return MIN(AD5258_RDAC_MAX, ret);
};

int8_t actuation_point_write_rdac(uint8_t value) {
    value = MIN(AD5258_RDAC_MAX, value);
    i2c_status_t e = i2c_write_register(AD5258_ADDR, AD5258_INST_RDAC, &value, 1, ACTUATION_POINT_I2C_TIMEOUT);
    if (e == I2C_STATUS_SUCCESS) {
        return value;
    } else if (e == I2C_STATUS_TIMEOUT) {
        dprintf("actuation_point_write_rdac: timeout\n");
    } else if (e == I2C_STATUS_ERROR) {
        dprintf("actuation_point_write_rdac: error\n");
    }

    return -1;
};

int8_t actuation_point_adjust(int8_t offset) {
    int8_t r = -1;
    int8_t rdac = actuation_point_read_rdac();

    if (rdac >= 0) {
        uint8_t rdac_new = rdac + offset;

        if (offset > 0) {
            r = actuation_point_write_rdac(MIN(AD5258_RDAC_MAX, rdac_new));
        } else if (offset < 0) {
            r = actuation_point_write_rdac(MAX(AD5258_RDAC_MIN, rdac_new));
        }
    }

    return r;
}

int8_t actuation_point_make_shallower(void) {
    return actuation_point_adjust(-1);
};

int8_t actuation_point_make_deeper(void) {
    return actuation_point_adjust(1);
};

void actuation_point_reset(void) {
    i2c_status_t e = i2c_write_register(AD5258_ADDR, AD5258_INST_RESTORE, NULL, 0, ACTUATION_POINT_I2C_TIMEOUT);
    if (e == I2C_STATUS_TIMEOUT) {
        dprintf("actuation_point_reset: timeout\n");
    } else if (e == I2C_STATUS_ERROR) {
        dprintf("actuation_point_reset: error\n");
    } else {
        wait_us(350); // datasheet specifies 300us restore interval
        i2c_write_register(AD5258_ADDR, AD5258_INST_NOP, NULL, 0, ACTUATION_POINT_I2C_TIMEOUT); // recommended in datasheet
    }
}

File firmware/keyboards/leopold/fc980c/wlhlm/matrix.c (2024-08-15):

// Copyright 2024 Wilhelm Schuster
// Copyright 2019 Evy Dekkers
// Copyright 2012-2018 Jun Wako, Jack Humbert, Yiancar
// SPDX-License-Identifier: GPL-2.0-or-later

#include "matrix.h"
#include "gpio.h"
#include "util.h"
#include "wait.h"

static const pin_t row_pins[] = MATRIX_MUX_ROW_PINS;
static const pin_t col_pins[] = MATRIX_MUX_COL_PINS;

static inline void KEY_ENABLE_on(void) { gpio_write_pin_low(MATRIX_KEY_ENABLE_PIN); }
static inline void KEY_ENABLE_off(void) { gpio_write_pin_high(MATRIX_KEY_ENABLE_PIN); }
static inline void KEY_HYS_on(void) { gpio_write_pin_high(MATRIX_KEY_HYS_PIN); }
static inline void KEY_HYS_off(void) { gpio_write_pin_low(MATRIX_KEY_HYS_PIN); }

static void set_row(int row) {
    gpio_write_pin(row_pins[0], row & 0b00000001);
    gpio_write_pin(row_pins[1], row & 0b00000010);
    gpio_write_pin(row_pins[2], row & 0b00000100);
}

static void set_col(int col) {
    gpio_write_pin(col_pins[0], col & 0b00000001);
    gpio_write_pin(col_pins[1], col & 0b00000010);
    gpio_write_pin(col_pins[2], col & 0b00000100);
    gpio_write_pin(col_pins[3], col & 0b00001000);
}

static bool read_rows_on_col(matrix_row_t current_matrix[], int current_col) {
    bool matrix_changed = false;

    set_col(current_col);

    for (int row_index = 0; row_index < MATRIX_ROWS; row_index++) {
        // store last value of row prior to reading
        matrix_row_t last_row_value = current_matrix[row_index];

        set_row(row_index);

        if (last_row_value & (1 << current_col)) {
            KEY_HYS_on();
        }
        matrix_output_select_delay();

        KEY_ENABLE_on();
        wait_us(2);

        // KEY_STATE is only valid for 20us after KEY_ENABLE
        if (!gpio_read_pin(MATRIX_KEY_STATE_PIN)) {
            // pin LO, set col bit
            current_matrix[row_index] |= (MATRIX_ROW_SHIFTER << current_col);
        } else {
            // pin HI, clear col bit
            current_matrix[row_index] &= ~(MATRIX_ROW_SHIFTER << current_col);
        }

        KEY_HYS_off();
        KEY_ENABLE_off();

        // KEY_STATE keeps its state for 20us after KEY_ENABLE. Wait for 25us or
        // more to make sure KEY_STATE returns to idle state.
        wait_us(25);

        // determine if the matrix changed state
        if ((last_row_value != current_matrix[row_index]) && !(matrix_changed)) {
            matrix_changed = true;
        }
    }

    return matrix_changed;
}

void matrix_init_custom(void) {
    gpio_set_pin_input(MATRIX_KEY_STATE_PIN); // uses external pullup
    gpio_set_pin_output(MATRIX_KEY_HYS_PIN);
    gpio_set_pin_output(MATRIX_KEY_ENABLE_PIN);

    for (int i = 0; i < ARRAY_SIZE(row_pins); i++) {
        gpio_set_pin_output(row_pins[i]);
    }
    for (int i = 0; i < ARRAY_SIZE(col_pins); i++) {
        gpio_set_pin_output(col_pins[i]);
    }

    KEY_ENABLE_off();
    KEY_HYS_off();
}

bool matrix_scan_custom(matrix_row_t current_matrix[]) {
    bool changed = false;

    for (uint8_t current_col = 0; current_col < MATRIX_COLS; current_col++) {
        changed |= read_rows_on_col(current_matrix, current_col);
    }

    return changed;
}

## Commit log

2022-12-18 rev1: Add EEPROM
    This should alleviate needing to use MCU flash for EEPROM emulation.
    Also recalculate crystal load capacitor values using guidance from the
    MCU datasheet.
    [fc980c-controller.kicad_pcb, fc980c-controller.kicad_sch]
2022-12-18 rev1: Small tweaks after test submitting to JLC
    Fix some component rotations and tweak top GND copper zone near the
    edge.
    [fc980c-controller.kicad_pcb]
2022-12-20 rev1: Minor tweaks before first production run
    Most notably change to a capacitor footprint rather than resistor
    footprint for C6.
    Small via tweaks.
    Adjust component rotations reviewing JLC SMTA preview. (still waiting on
    JLC review at this point)
    [fc980c-controller.kicad_pcb, fc980c-controller.kicad_sch]
2022-12-20 Adjust gitignore for files generated by the KiCad JLC plugin
2022-12-22 rev1: Final production files for first run
    Last tweak is to add tooling holes necessary for JLC PCB assembly. JLC
    will place them on their own, however in their first attempt put one
    hole over the silkscreen, so placing them manually should prevent this
    in the future.
    [BOM-fc980c-controller.csv, fc980c-controller.kicad_pcb, fc980c-controller.kicad_sch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]
2023-01-02 rev2: Fix SWDIO MCU pin
    Didn't take long to find flaws in the revision 1 design. SWDIO is
    erroneously hooked up to PA15 on the MCU instead of PA13.
    [fc980c-controller.kicad_pcb, fc980c-controller.kicad_sch]
2023-01-02 rev2: Explain oscillator frequency choice
    [fc980c-controller.kicad_sch]
2023-01-02 rev2: Update revision references in schematic and PCB
    [fc980c-controller.kicad_pcb, fc980c-controller.kicad_sch]
2023-01-02 rev2: Minor position adjustment to mounting drill holes
    [fc980c-controller.kicad_pcb]
2023-01-06 rev2: Copy files to new directory
    [fc980c-controller.kicad_pcb, fc980c-controller.kicad_sch]
2023-01-06 rev1: Revert rev2 changes
    [fc980c-controller.kicad_pcb, fc980c-controller.kicad_sch]
2023-01-06 rev2: Add 5V pull-up to KEY_STATE pin
    [fc980c-controller.kicad_pcb, fc980c-controller.kicad_sch]
2023-01-06 rev2: Drop I2C level shifter
    Upon further review, using a 5V I2C bus should be unproblematic with a
    5V tolerant MCU due to the open-drain design.
    [fc980c-controller.kicad_pcb, fc980c-controller.kicad_sch]
2023-01-08 Remove mentions of the I2C level shifter from README
2023-01-08 rev2: Exclude some components from BOM
    [fc980c-controller.kicad_pcb]
2023-01-08 rev2: Add "MCU" silkscreen
    [fc980c-controller.kicad_pcb]
2023-01-08 rev2: Rotate SWD header 3D model
    [fc980c-controller.kicad_pcb]
2023-01-08 rev2: Add schematic PDF export
2023-01-08 firmware: Replace tabs with spaces
    [actuation_point.c, matrix.c]
2023-01-08 rev2: Add production files
    [BOM-fc980c-controller.csv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]
2023-01-08 Add photos of prototype rev1 PCB
2023-01-08 firmware: Fix README make example command
    [matrix.c]
2023-01-30 firmware: Replace uprintf with dprintf
    [actuation_point.c]
2024-08-15 firmware: Update QMK I2C API
2024-08-15 firmware: Define bootmagic and EEPROM driver in info.json
2024-09-09 rev2: Fix typo in schematic
    [fc980c-controller.kicad_sch]

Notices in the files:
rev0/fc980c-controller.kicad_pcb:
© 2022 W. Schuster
